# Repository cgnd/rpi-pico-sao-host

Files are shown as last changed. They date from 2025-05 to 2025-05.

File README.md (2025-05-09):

---
typora-copy-images-to: ./images
---

# Raspberry Pi Pico SAO Host

The [Raspberry Pi Pico SAO Host](https://github.com/cgnd/rpi-pico-sao-host) is a breakout board that adds [Simple Add-on (SAO)](https://hackaday.io/project/175182-simple-add-ons-sao) host connectors to the [Raspberry Pi Pico](https://www.raspberrypi.com/products/raspberry-pi-pico/).

## v2 Design (latest)

The `v2` design adds the following features:

* A power switch (`SW2`) attached to the the Pico's `3V3_EN` input pin.
* A power LED (`D1`) that turns on when the Pico is powered on.
* A tactile reset switch (`SW1`) connected to the Pico's `RUN` input pin.

See the [CHANGELOG](CHANGELOG.md) for a full list of the changes from the previous version.

**Top (Primary) Side**

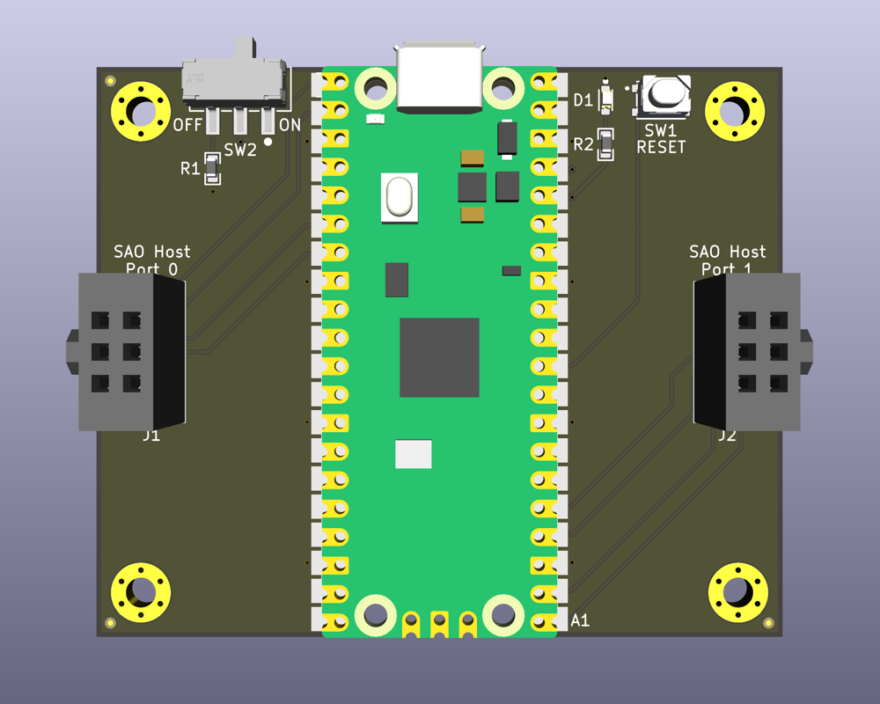
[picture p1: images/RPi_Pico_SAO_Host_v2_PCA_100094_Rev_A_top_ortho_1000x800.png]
RPi_Pico_SAO_Host_v2_PCA_100094_Rev_A_top_ortho_1000x800


**Bottom (Secondary) Side**

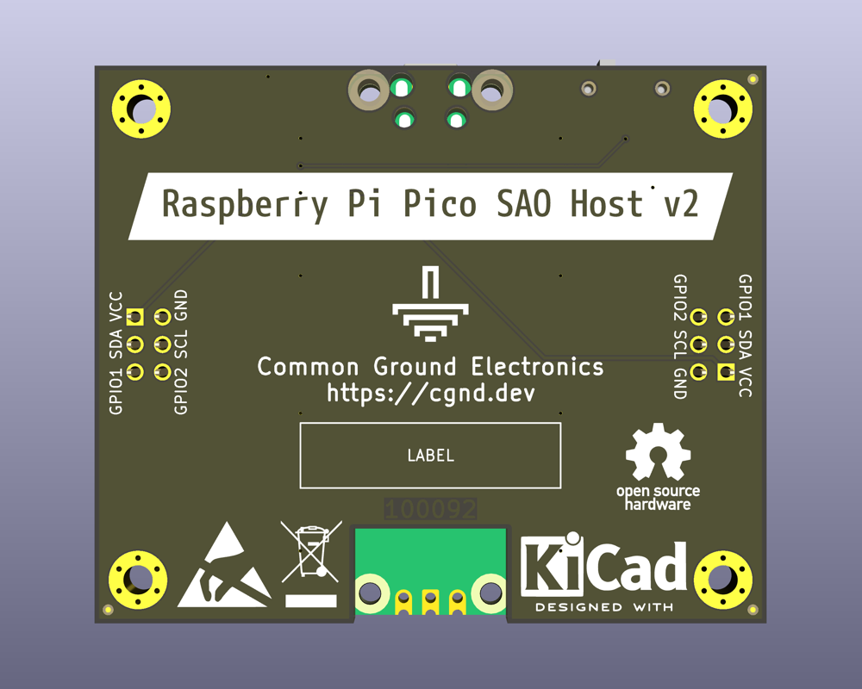
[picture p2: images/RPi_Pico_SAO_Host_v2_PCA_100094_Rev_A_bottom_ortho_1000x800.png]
RPi_Pico_SAO_Host_v2_PCA_100094_Rev_A_bottom_ortho_1000x800


### Checking out the design

To check out the design, [download the zip](https://github.com/cgnd/rpi-pico-sao-host/archive/refs/heads/v2.zip) or clone the repository using Git.

```sh
git clone https://github.com/cgnd/rpi-pico-sao-host.git
```

Open the the [RPi_Pico_SAO_Host.kicad_pro](RPi_Pico_SAO_Host.kicad_pro) project file in KiCad (requires version 9 or later).

## v1 Design

See the [README](https://github.com/cgnd/rpi-pico-sao-host/blob/v1/README.md) on the [v1](https://github.com/cgnd/rpi-pico-sao-host/tree/v1) branch for information about the `v1` design.

## License

See the [LICENSE](LICENSE.md) file for copyright & license information.

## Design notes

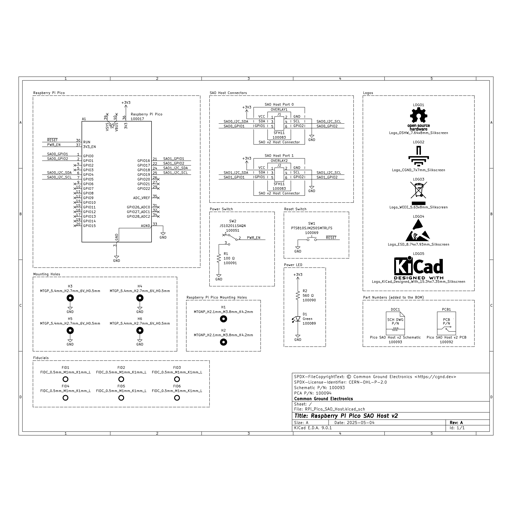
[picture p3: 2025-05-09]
images/RPi_Pico_SAO_Host_v2_Schematic_100093_Rev_A_512x512.png

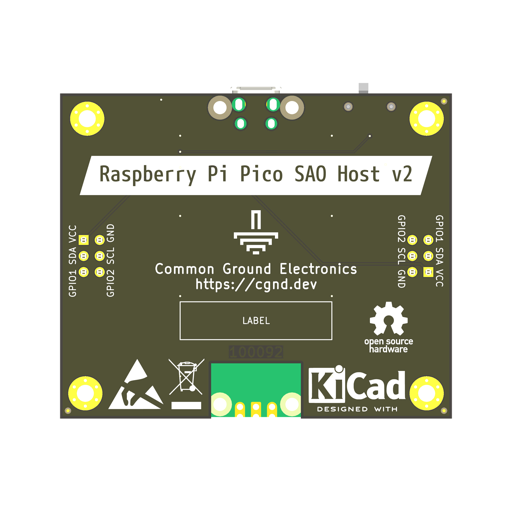
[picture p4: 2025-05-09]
images/RPi_Pico_SAO_Host_v2_PCA_100094_Rev_A_bottom_512x512.png

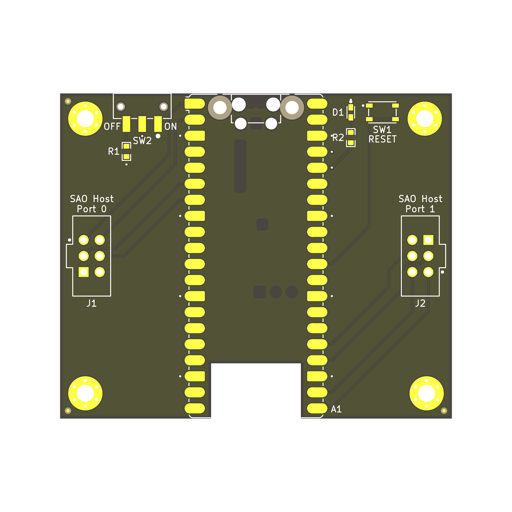
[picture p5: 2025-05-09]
images/RPi_Pico_SAO_Host_v2_PCB_100092_Rev_A_top_512x512.png

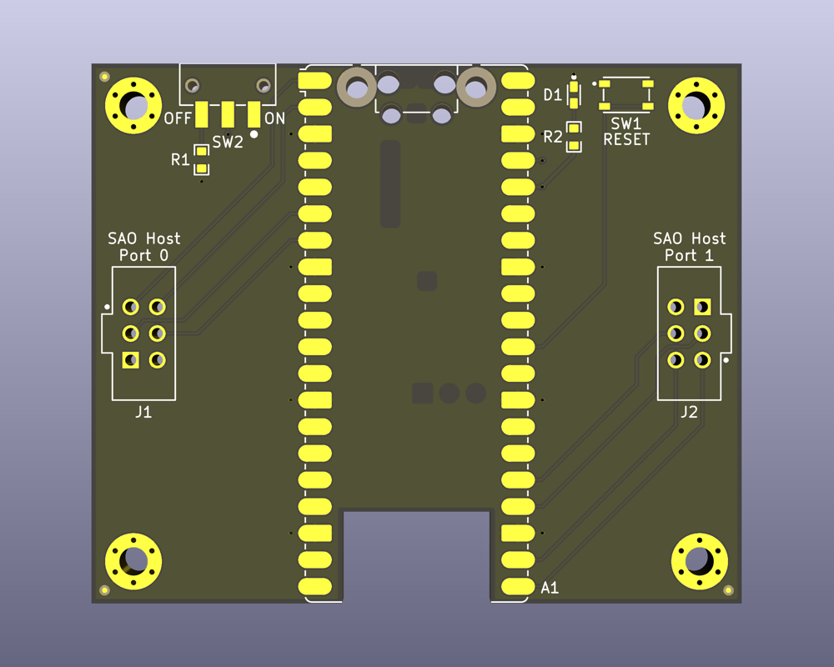
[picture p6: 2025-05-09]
images/RPi_Pico_SAO_Host_v2_PCB_100092_Rev_A_top_ortho_1000x800.png

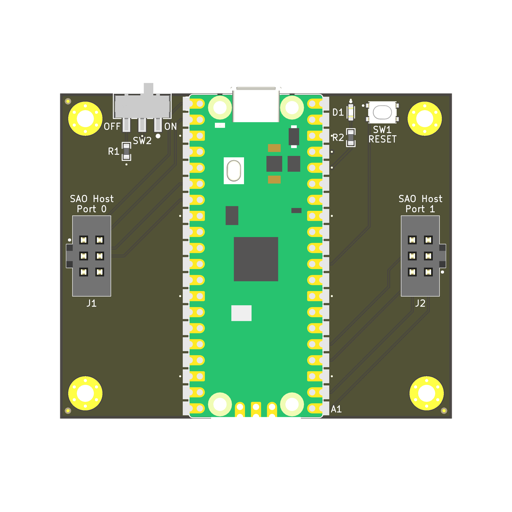
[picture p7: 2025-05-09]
images/RPi_Pico_SAO_Host_v2_PCA_100094_Rev_A_top_512x512.png

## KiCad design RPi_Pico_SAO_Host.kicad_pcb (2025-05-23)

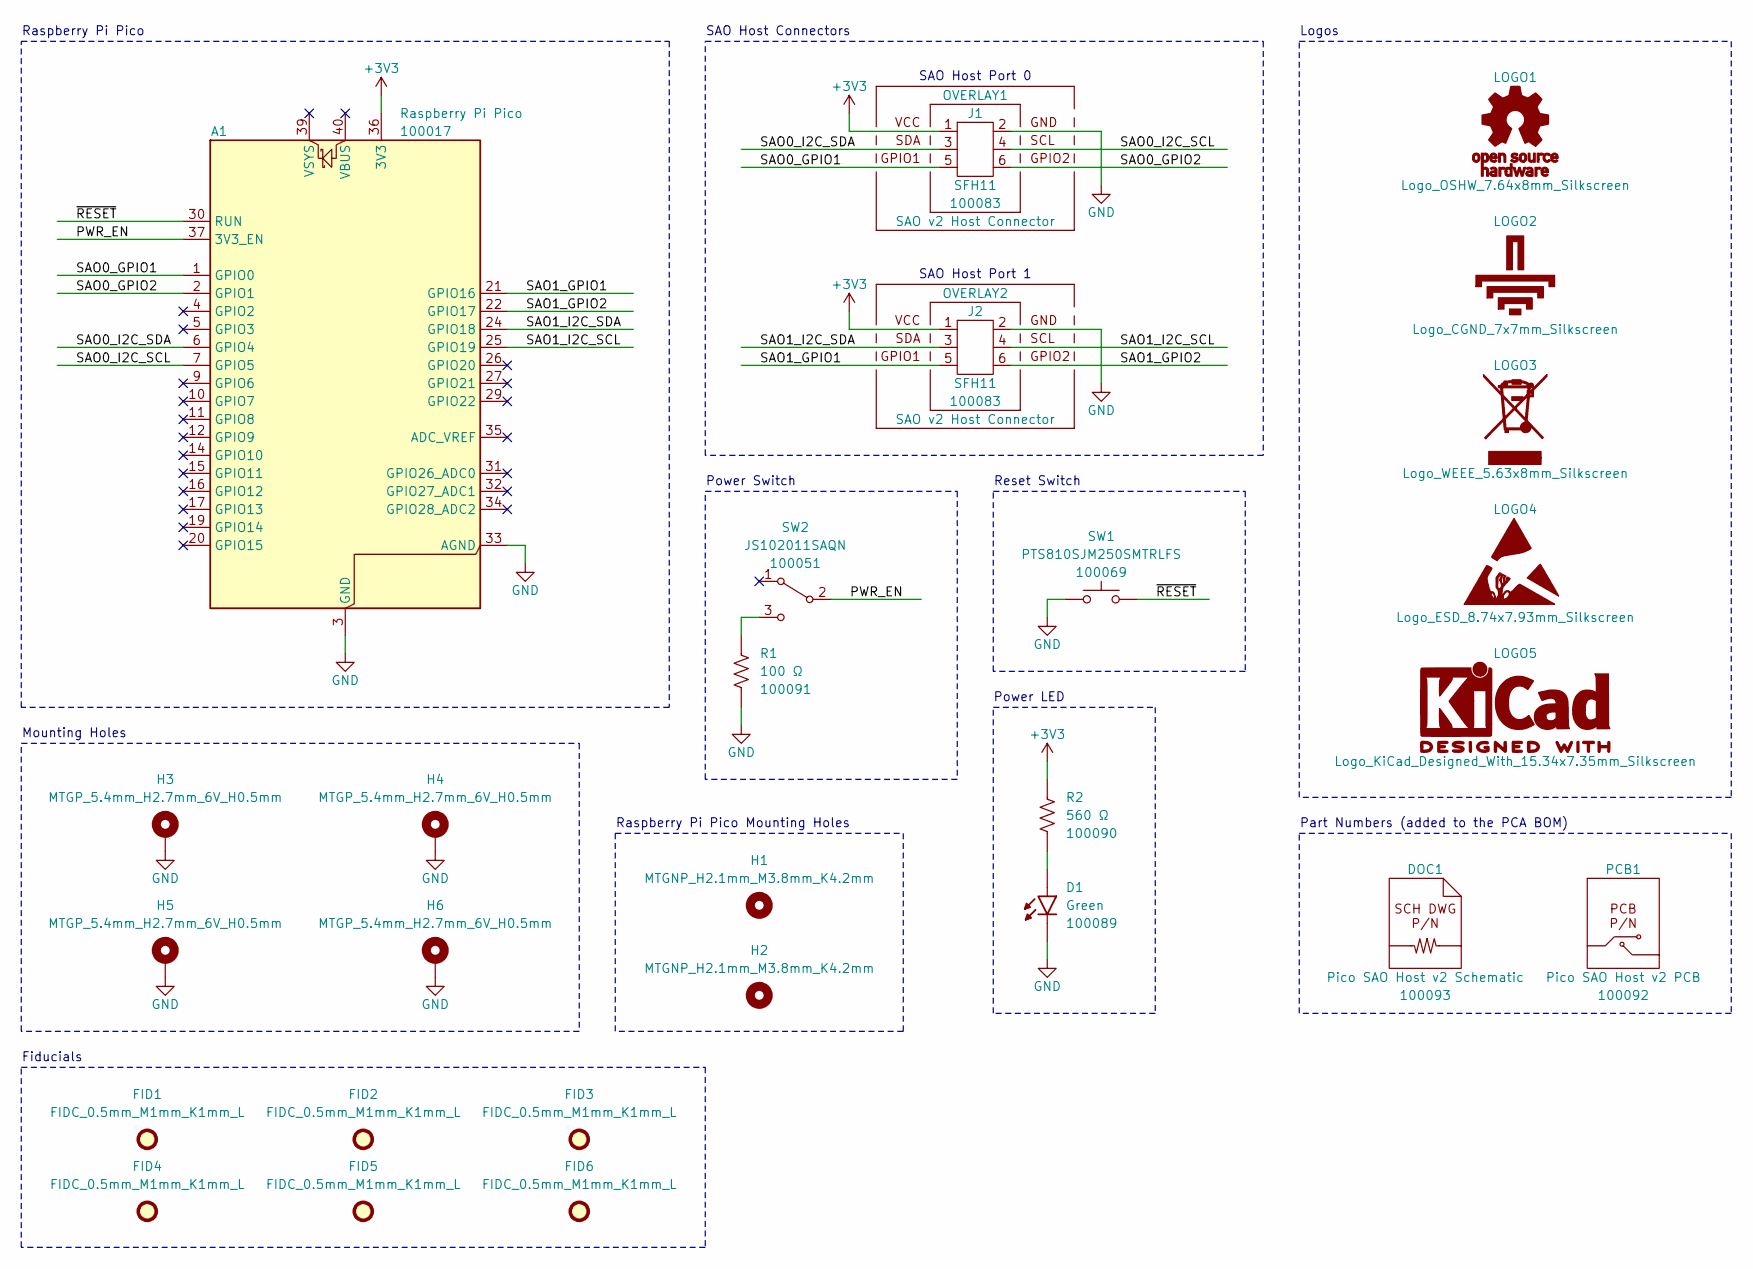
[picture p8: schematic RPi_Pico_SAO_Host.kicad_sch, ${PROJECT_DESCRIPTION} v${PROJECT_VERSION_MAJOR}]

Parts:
A1: Raspberry Pi Pico; Raspberry_Pi_Pico_Common_SMD
D1: Green; LEDSC_0603_0.8x1.6x0.8mm_L0.45x0.7mm_N
DOC1: Pico SAO Host v2 Schematic
FID1, FID2, FID3, FID4, FID5, FID6: FIDC_0.5mm_M1mm_K1mm_L
H1, H2: MTGNP_H2.1mm_M3.8mm_K4.2mm
H3, H4, H5, H6: MTGP_5.4mm_H2.7mm_6V_H0.5mm
J1, J2: SFH11; Sullins_SFH11-xxxC-D03-ST-BK
LOGO1: Logo_OSHW_7.64x8mm_Silkscreen
LOGO2: Logo_CGND_7x7mm_Silkscreen
LOGO3: Logo_WEEE_5.63x8mm_Silkscreen
LOGO4: Logo_ESD_8.74x7.93mm_Silkscreen
LOGO5: Logo_KiCad_Designed_With_15.34x7.35mm_Silkscreen
OVERLAY1, OVERLAY2: SAO v2 Host Connector; Overlay_SAO_v2_Host
PCB1: Pico SAO Host v2 PCB
R1: 100 Ω; RESC_0603_1.6x0.8x0.55mm_L0.25mm_N
R2: 560 Ω; RESC_0603_1.6x0.8x0.55mm_L0.25mm_N
SW1: PTS810SJM250SMTRLFS; CK_PTS810SJx250
SW2: JS102011SAQN; CK_JS102011SAxN

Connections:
+3V3: A1.36 (3V3), J1.1, J2.1, R2.1
/PWR_EN: A1.37 (3V3_EN), SW2.2 (B)
/SAO0_GPIO1: A1.1 (GPIO0), J1.5
/SAO0_GPIO2: A1.2 (GPIO1), J1.6
/SAO0_I2C_SCL: A1.7 (GPIO5), J1.4
/SAO0_I2C_SDA: A1.6 (GPIO4), J1.3
/SAO1_GPIO1: A1.21 (GPIO16), J2.5
/SAO1_GPIO2: A1.22 (GPIO17), J2.6
/SAO1_I2C_SCL: A1.25 (GPIO19), J2.4
/SAO1_I2C_SDA: A1.24 (GPIO18), J2.3
/~RESET: A1.30 (RUN), SW1.2
GND: A1.3 (GND), A1.8 (GND), A1.13 (GND), A1.18 (GND), A1.23 (GND), A1.28 (GND), A1.33 (AGND), A1.38 (GND), D1.C (Cathode), H3.1, H4.1, H5.1, H6.1, J1.2, J2.2, R1.2, SW1.1
unnamed: D1.A (Anode), R2.2
unnamed: R1.1, SW2.3 (C)

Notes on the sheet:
Fiducials
SAO Host Port 0
Mounting Holes
Part Numbers (added to the PCA BOM)
Power Switch
Logos
Power LED
SAO Host Port 1
Raspberry Pi Pico Mounting Holes
Reset Switch
SAO Host Connectors
Raspberry Pi Pico

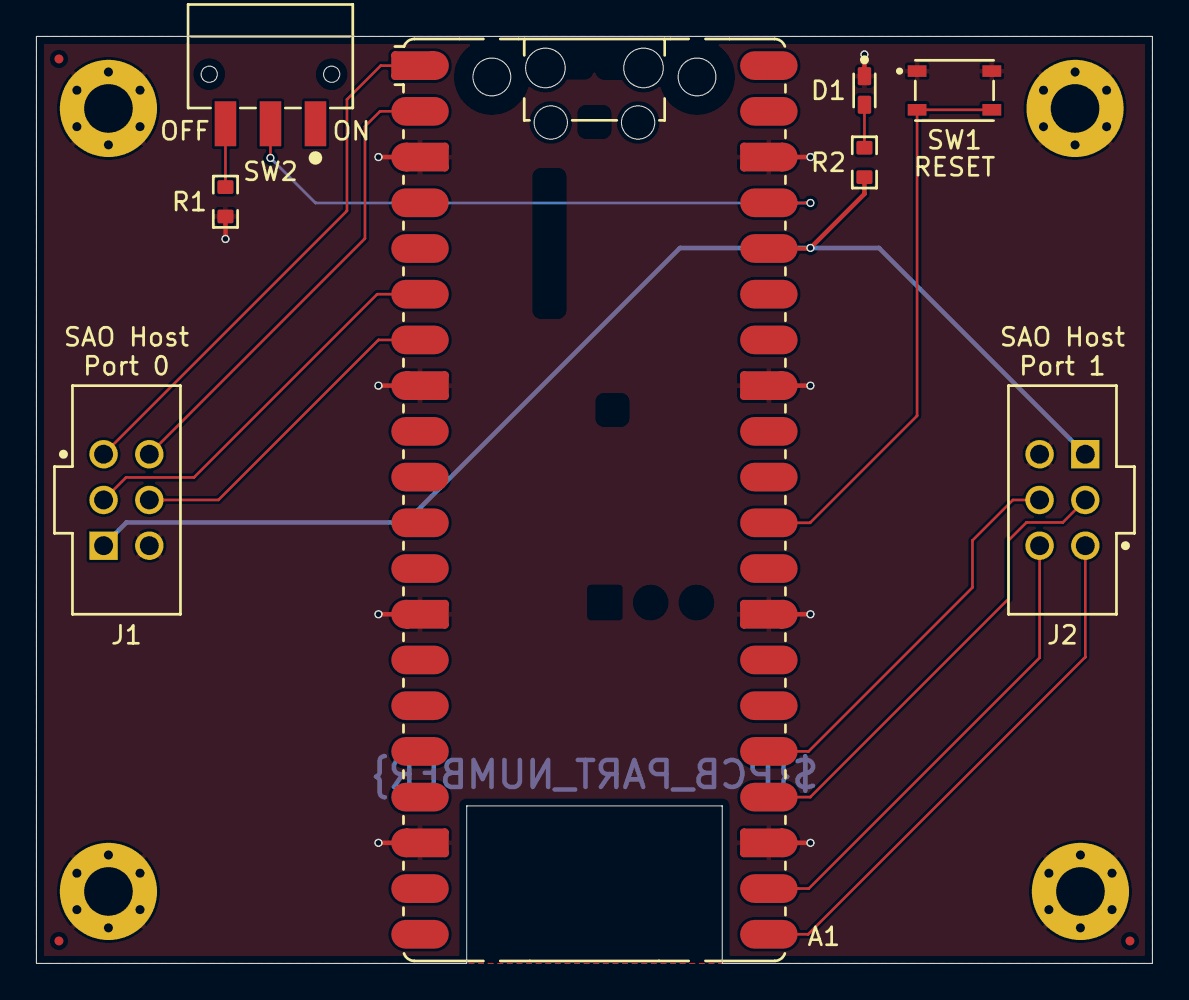
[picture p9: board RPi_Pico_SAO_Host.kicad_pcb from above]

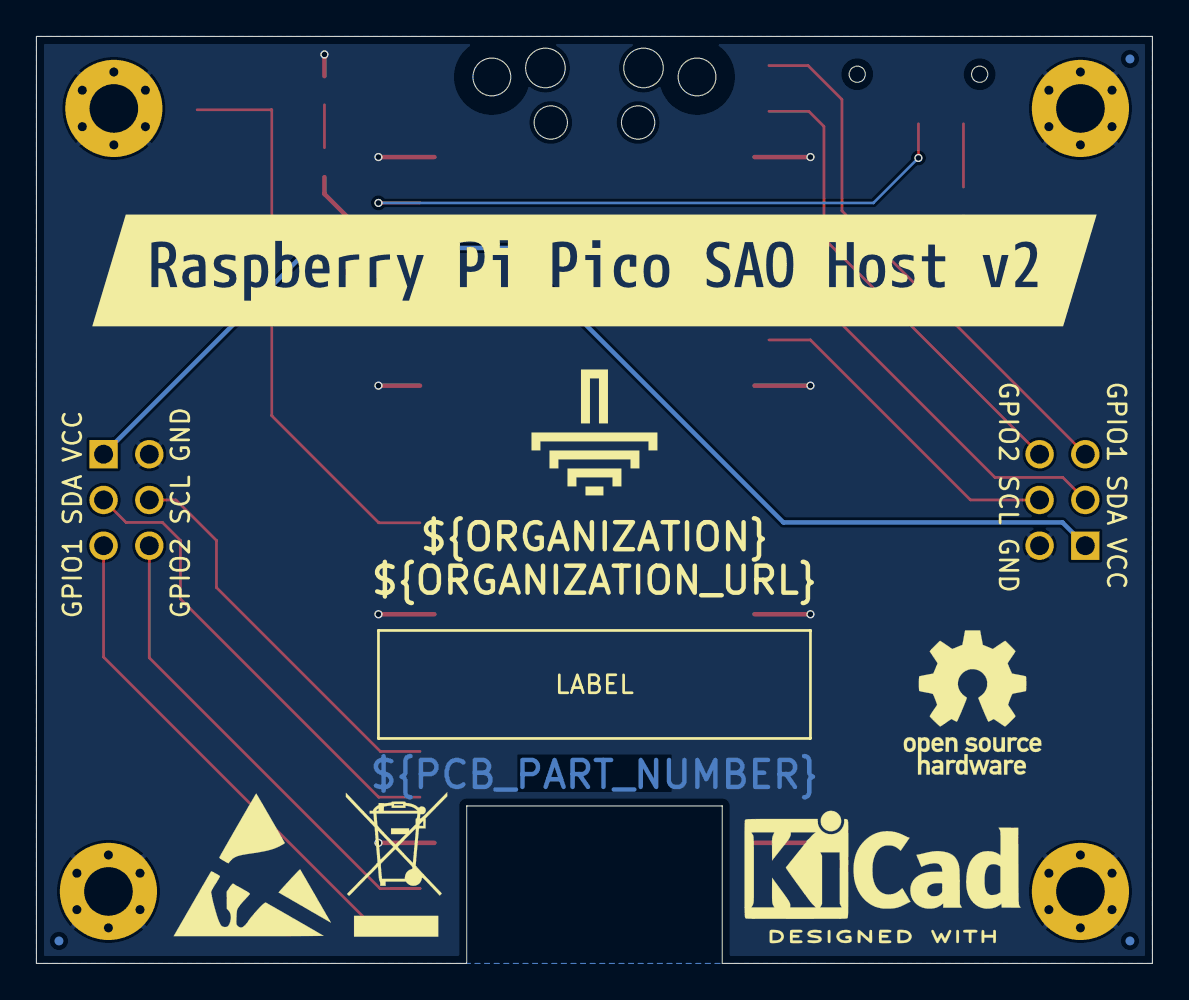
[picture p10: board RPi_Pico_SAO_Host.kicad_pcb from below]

Board: 2 copper layers, 62.0 x 51.5 mm, 28 parts (9 on the bottom side), 14 nets.

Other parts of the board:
kibuzzard-68151D09: VAL**; kibuzzard-68151D09

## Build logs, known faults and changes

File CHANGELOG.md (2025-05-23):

# Changelog

All notable changes to this project will be documented in this file.

The format is based on [Keep a Changelog](https://keepachangelog.com/en/1.1.0/).

## [Unreleased]

### Fixed

- Remove old copyright & license fields.
- Clean up KiCad project file.
- Remove old library setup instructions from CONTRIBUTING.md.

### Changed

- Remove hard-coded project metadata from tasks.py.
- Update `CGND_OSHW_IPN` library URI (the path was changed in a library update).
- Remove `Symbol` field from symbols and footprints.
- Update [cgnd-kicad-lib](https://github.com/cgnd/cgnd-kicad-lib/) library.

## [2.0.1] - 2025-05-12

### Added

- Add mounting hole outlines to `*.Fab` and `*.Assembly` layers.

### Fixed

- Fix missing layers in `kicad-cli` exports.
- Fix layer types for `F.Fab` and `B.Fab` layers.

### Changed

- Change PCB revision to `B`.

## [2.0.0] - 2025-05-09

### Added

- Add a power switch (`SW2`) attached to the the Pico's `3V3_EN` input pin.
- Add a power LED (`D1`) that turns on when the Pico is powered on.
- Add a tactile reset switch (`SW1`) connected to the Pico's `RUN` input pin (#2).
- Add a project management CLI using [Invoke](https://www.pyinvoke.org/) task runner.

### Fixed

- Switch Pico footprint to fix castellated test point issues on `v1` design (#3).

### Changed

- Migrate the design to use the [CGND KiCad Library](https://github.com/cgnd/cgnd-kicad-lib/) and internal part numbers managed by the https://cgnd-oshw.aligni.com Aligni PLM instance.

## [1.0.0] - 2025-05-04

Initial release of the `v1` design files.

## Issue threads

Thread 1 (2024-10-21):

Support for RPi Pico "H" variants

cdwilson, 2024-10-21:
Rev 1 only supports mounting the SMD variants of the RPi Pico boards. Updating the Pico footprint to support installing through hole sockets (like https://www.adafruit.com/product/5583) would allow the board to be used with the "H" variants of the RPi Pico boards.

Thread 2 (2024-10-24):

Add a reset button

cdwilson, 2024-10-24:
The RPi Pico boards don't have a reset button built in. It would be nice to have one on the carrier board so you don't have to unplug the USB cable to reset the board.

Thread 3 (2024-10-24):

Switch to Pico footprint without castellated test point connections

cdwilson, 2024-10-24:
The Rev 1 board has an experimental footprint which provides hand-solder access to the test point pads on the bottom of the Pico boards.

I didn't realize that the `TP4`/`TP5`/`TP6` test points on the Pico W are placed in a different location vs. the test points on the Pico or Pico 2, so the Pico W is not compatible with the Rev 1 board.

On the next rev, this footprint should be changed to a standard footprint which does not use these castellated test points.

cdwilson, 2024-10-26:
Upstream issue: https://gitlab.com/recursivenomad/ki-lime-pi-pico/-/issues/2

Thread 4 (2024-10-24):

Larger OSHW logo

cdwilson, 2024-10-24:
There is space for a larger/more legible OSHW logo on the board.

cdwilson, 2025-05-06:
Added in the [1.0.0](https://github.com/cgnd/rpi-pico-sao-host/releases/tag/v1.0.0) release.

Closed 2025-05-06.

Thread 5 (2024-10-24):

Add board name to the PCB silkscreen

cdwilson, 2024-10-24:
I forgot to add the name of the board to the PCB silkscreen on the Rev 1 board.

cdwilson, 2025-05-06:
Added in the [1.0.0](https://github.com/cgnd/rpi-pico-sao-host/releases/tag/v1.0.0) release.

Closed 2025-05-06.

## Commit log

2024-10-15 Add 100081 Rev 1 schematic and layout
    [rpi-pico-sao-host.kicad_pcb, rpi-pico-sao-host.kicad_sch]
2024-10-15 Update schematic export settings
2024-10-26 Add incompatibility note to README for Pico W
2025-05-04 Update v1 project layout and revision scheme
    [RPi_Pico_SAO_Host.kicad_pcb, RPi_Pico_SAO_Host.kicad_sch, rpi-pico-sao-host.kicad_pcb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]
2025-05-04 Fix issue date in PCB title block
    [RPi_Pico_SAO_Host.kicad_pcb]
2025-05-09 Add v2 design changes
    [RPi_Pico_SAO_Host.kicad_pcb, RPi_Pico_SAO_Host.kicad_sch]
2025-05-12 Fix layer types for F.Fab and B.Fab layers
    [RPi_Pico_SAO_Host.kicad_pcb]
2025-05-12 Fix missing layers in kicad-cli exports
2025-05-12 Add mounting hole outlines on Fab layers
    [RPi_Pico_SAO_Host.kicad_pcb]
2025-05-12 Add mounting hole outlines to Assembly layers
    [RPi_Pico_SAO_Host.kicad_pcb]
2025-05-12 Change PCB revision to 'B'
    [RPi_Pico_SAO_Host.kicad_pcb]
2025-05-15 Remove old copyright & license fields
    [RPi_Pico_SAO_Host.kicad_pcb, RPi_Pico_SAO_Host.kicad_sch]
2025-05-16 Clean up KiCad project file
2025-05-23 Remove Symbol field from symbols and footprints
    [RPi_Pico_SAO_Host.kicad_pcb, RPi_Pico_SAO_Host.kicad_sch]
2025-05-23 Update cgnd-kicad-lib

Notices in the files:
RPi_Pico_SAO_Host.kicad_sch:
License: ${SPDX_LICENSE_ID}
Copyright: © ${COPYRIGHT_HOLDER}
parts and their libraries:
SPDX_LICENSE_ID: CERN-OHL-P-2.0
